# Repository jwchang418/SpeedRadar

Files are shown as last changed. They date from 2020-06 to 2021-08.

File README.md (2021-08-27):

# SpeedRadar

This project is designed by Jun-Wei Chang for a simple speed radar by using a few of electronic components.

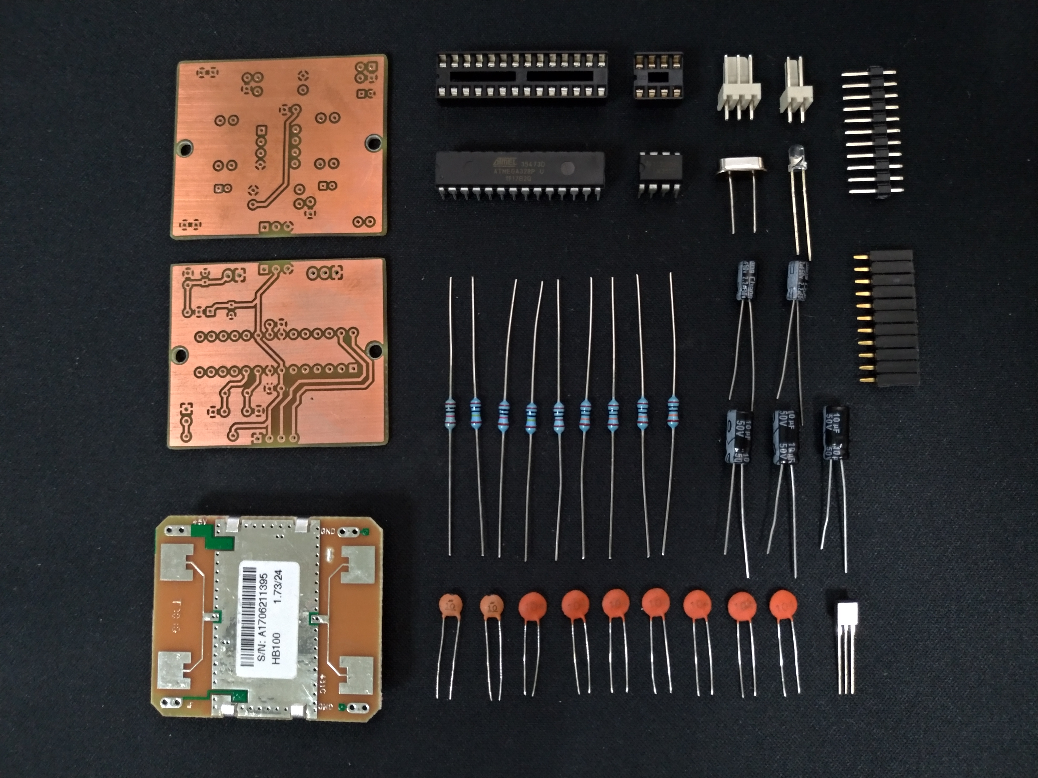
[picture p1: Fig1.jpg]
<br/>

Components list  
[here](https://github.com/jwchang418/SpeedRadar/blob/master/Components%20List.pdf)<br/>

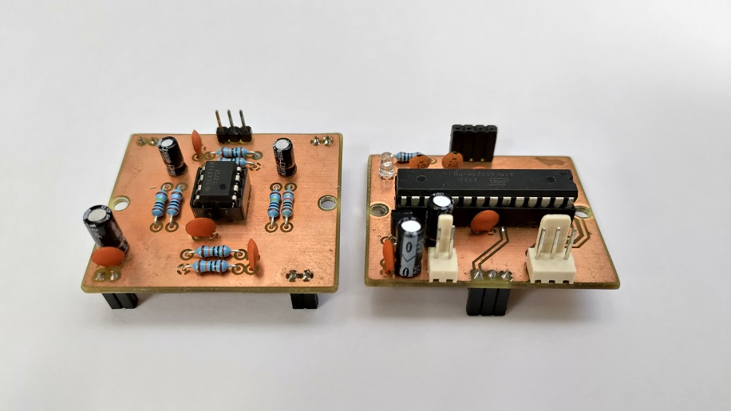
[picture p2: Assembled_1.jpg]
<br/>
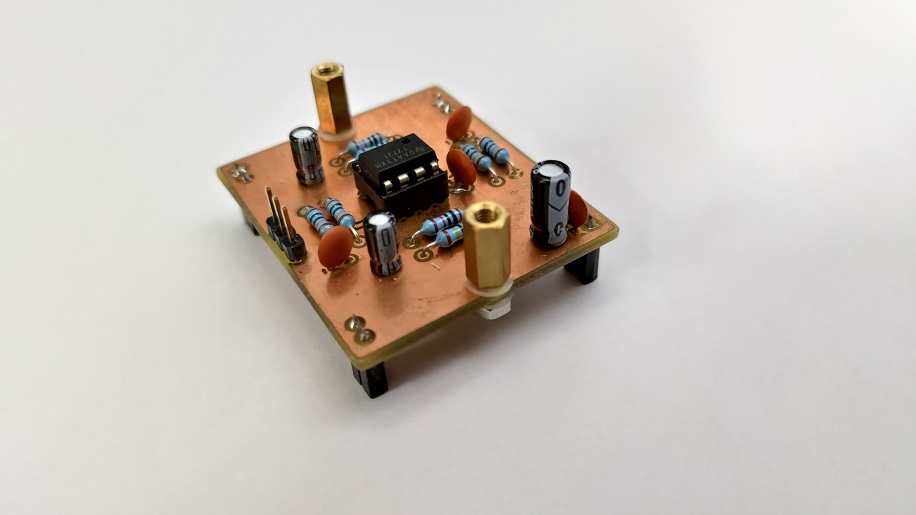
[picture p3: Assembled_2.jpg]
<br/>
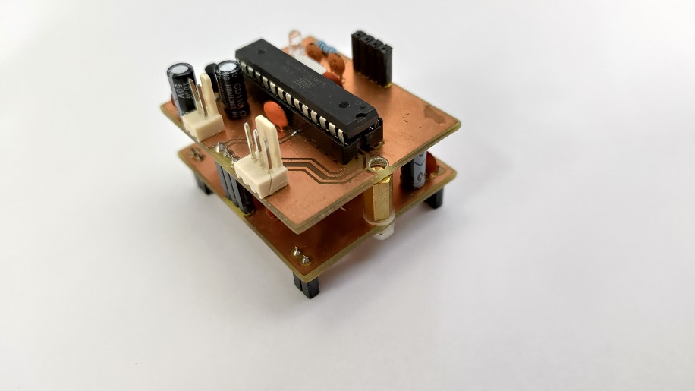
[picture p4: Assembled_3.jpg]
<br/>
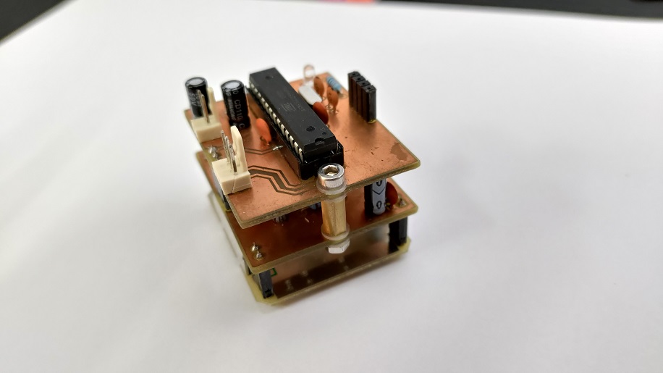
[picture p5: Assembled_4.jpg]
<br/>
Enjoy it !!

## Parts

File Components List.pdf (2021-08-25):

## Components List

Symbol | Value
C1 | 10uF
C2 | 0.1uF
C3 | 0.1uF
C4 | 0.1uF
C5 | 1uF
C6 | 0.1uF
C7 | 1uF
C8 | 0.1uF
C9 | 0.1uF
C10 | 10uF
C11 | 0.1uF
C12 | 10uF
C13 | 10pF
C14 | 10pF
D1 | LED
DC_in1 | 2 Pin Molex KK 254 Connector
HB1 | HB100
J1 | Conn_01x03
J2 | Conn_01x03
J3 | Conn_01x04
J4 | Conn_01x03
R1 | 100k
R2 | 100k
R3 | 10k
R4 | 1M
R5 | 100k
R6 | 100k
R7 | 10K
R8 | 200K
R9 | 1K
U1 | LM358
U2 | ATmega328P-PU
U3 | L78L05_TO92
Y1 | 16Mhz

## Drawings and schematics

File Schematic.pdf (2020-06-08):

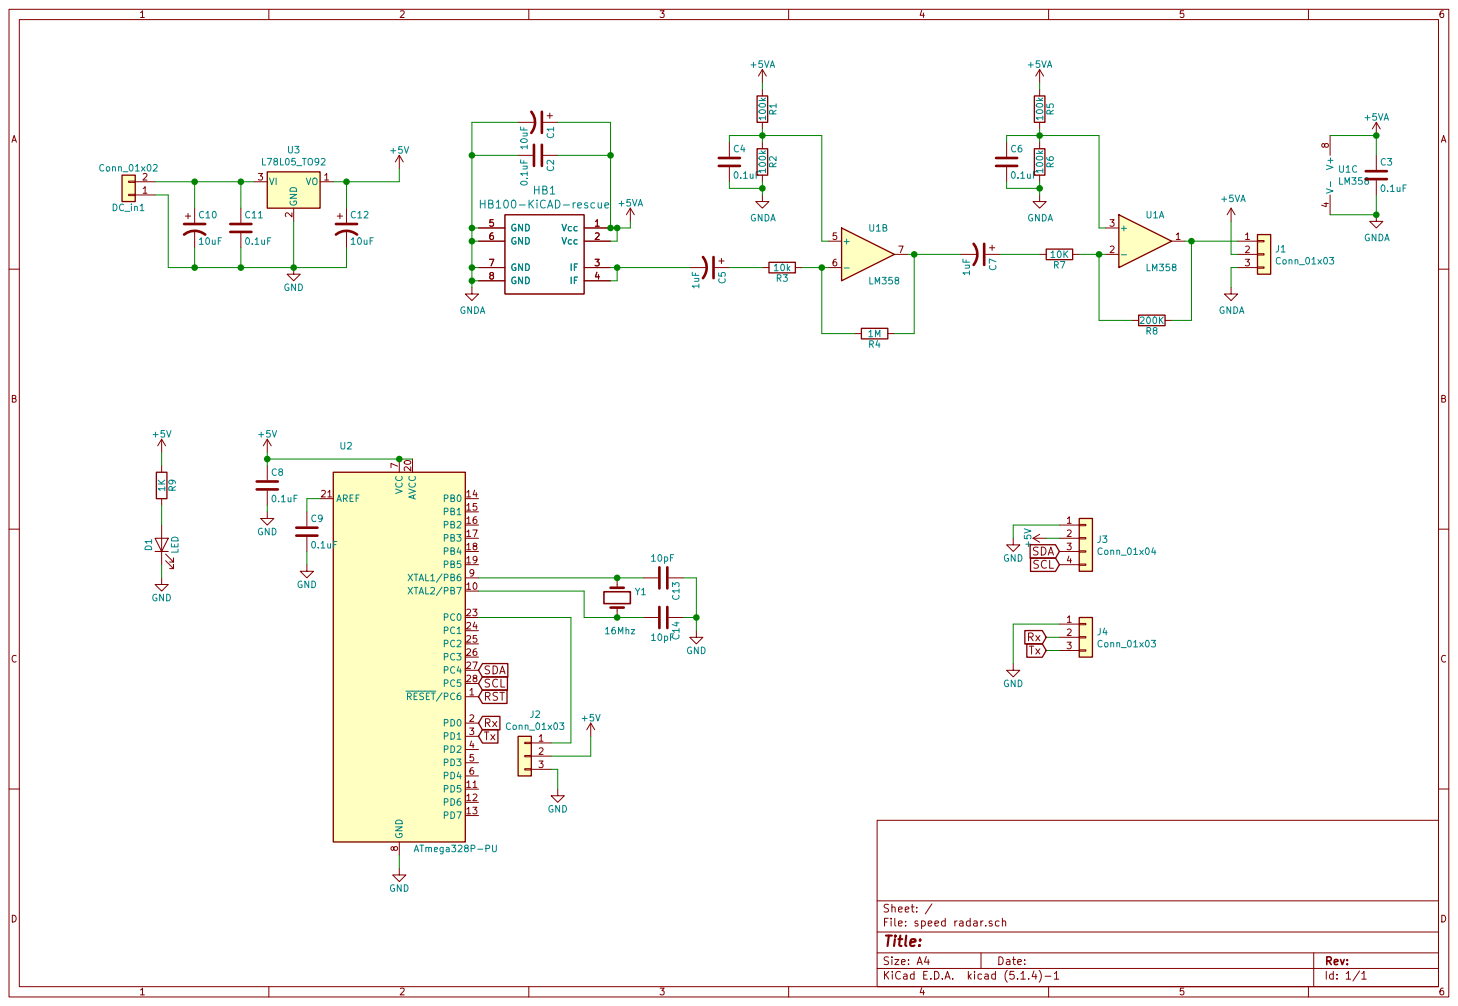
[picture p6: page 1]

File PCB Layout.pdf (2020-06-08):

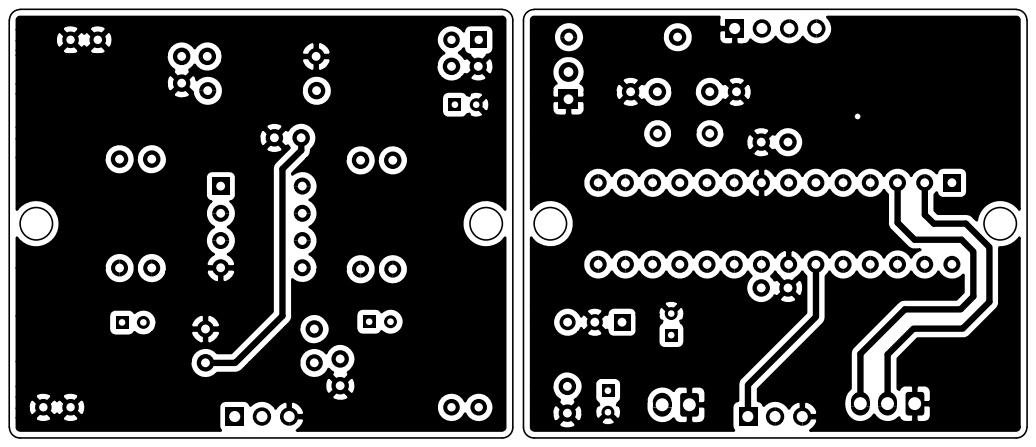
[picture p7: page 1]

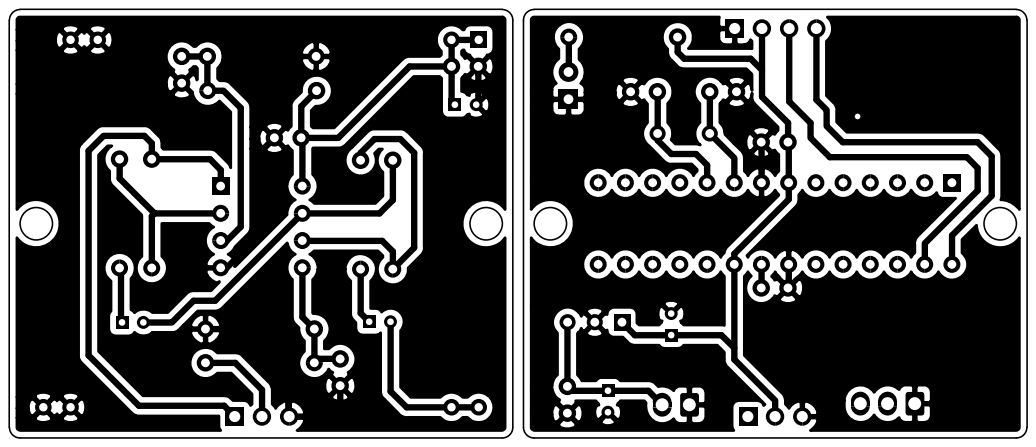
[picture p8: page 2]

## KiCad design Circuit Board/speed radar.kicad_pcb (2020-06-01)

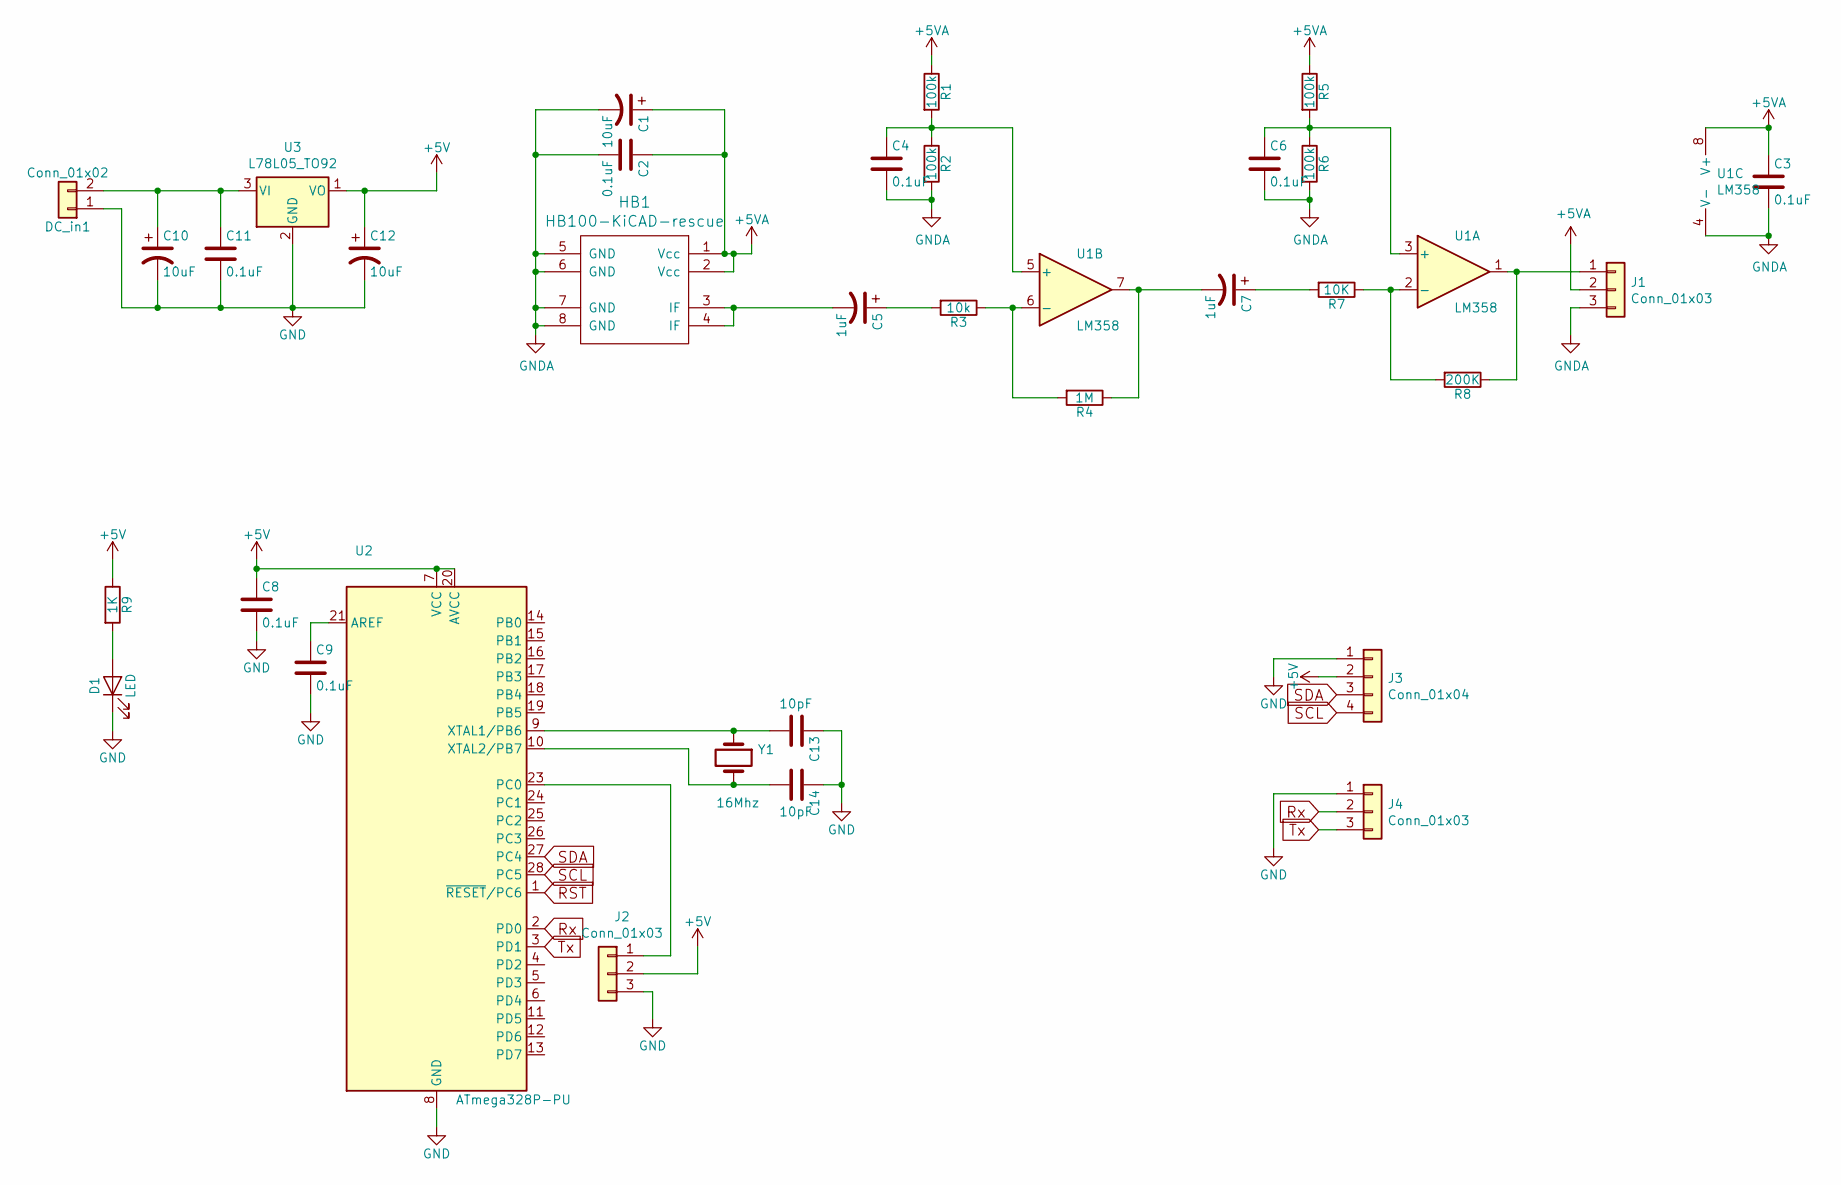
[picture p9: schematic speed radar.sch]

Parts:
C1, C10, C12: 10uF; CP_Radial_D4.0mm_P2.00mm
C2, C3, C4, C6, C8, C9, C11: 0.1uF; C_Disc_D3.0mm_W1.6mm_P2.50mm
C5, C7: 1uF; CP_Radial_D4.0mm_P2.00mm
C13, C14: 10pF; C_Disc_D3.0mm_W1.6mm_P2.50mm
D1: LED; LED_D3.0mm
DC_in1: Conn_01x02; Molex_KK-254_AE-6410-02A_1x02_P2.54mm_Vertical
HB1: HB100-KiCAD-rescue; HB100_ver2
J1, J2: Conn_01x03; PinHeader_1x03_P2.54mm_Vertical
J3: Conn_01x04; PinHeader_1x04_P2.54mm_Vertical
J4: Conn_01x03; Molex_KK-254_AE-6410-03A_1x03_P2.54mm_Vertical
R1, R2, R5, R6: 100k; R_Axial_DIN0207_L6.3mm_D2.5mm_P10.16mm_Horizontal
R3: 10k; R_Axial_DIN0207_L6.3mm_D2.5mm_P10.16mm_Horizontal
R4: 1M; R_Axial_DIN0207_L6.3mm_D2.5mm_P10.16mm_Horizontal
R7: 10K; R_Axial_DIN0207_L6.3mm_D2.5mm_P10.16mm_Horizontal
R8: 200K; R_Axial_DIN0207_L6.3mm_D2.5mm_P10.16mm_Horizontal
R9: 1K; R_Axial_DIN0207_L6.3mm_D2.5mm_P10.16mm_Horizontal
U1: LM358
U2: ATmega328P-PU; DIP-28_W7.62mm
U3: L78L05_TO92; TO-92_Inline_Wide
Y1: 16Mhz; Crystal_HC49-4H_Vertical

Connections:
+5V: C8.1, C12.1, J2.2, J3.2, R9.1, U2.7 (VCC), U2.20 (AVCC), U3.1 (VO)
+5VA: C1.1, C2.1, C3.1, HB1.1 (Vcc), HB1.2 (Vcc), J1.2, R1.1, R5.1, U1.8 (V+)
GND: C8.2, C9.2, C10.2, C11.2, C12.2, C13.1, C14.1, D1.1 (K), DC_in1.1, J2.3, J3.1, J4.1, U2.8 (GND), U2.22 (GND), U3.2 (GND)
GNDA: C1.2, C2.2, C3.2, C4.2, C6.2, HB1.5 (GND), HB1.6 (GND), HB1.7 (GND), HB1.8 (GND), J1.3, R2.2, R6.2, U1.4 (V-)
unnamed: C4.1, R1.2, R2.1, U1.5 (+)
unnamed: C5.1, R3.2
unnamed: C5.2, HB1.3 (IF), HB1.4 (IF)
unnamed: C6.1, R5.2, R6.1, U1.3 (+)
unnamed: C7.1, R7.2
unnamed: C7.2, R4.1, U1.7
unnamed: C9.1, U2.21 (AREF)
unnamed: C10.1, C11.1, DC_in1.2, U3.3 (VI)
unnamed: C13.2, U2.9 (XTAL1/PB6), Y1.1
unnamed: C14.2, U2.10 (XTAL2/PB7), Y1.2
unnamed: D1.2 (A), R9.2
unnamed: J1.1, R8.1, U1.1
unnamed: J2.1, U2.23 (PC0)
unnamed: R3.1, R4.2, U1.6 (-)
unnamed: R7.1, R8.2, U1.2 (-)
RST: U2.1 (~RESET~/PC6)
Rx: J4.2, U2.2 (PD0)
SCL: J3.4, U2.28 (PC5)
SDA: J3.3, U2.27 (PC4)
Tx: J4.3, U2.3 (PD1)

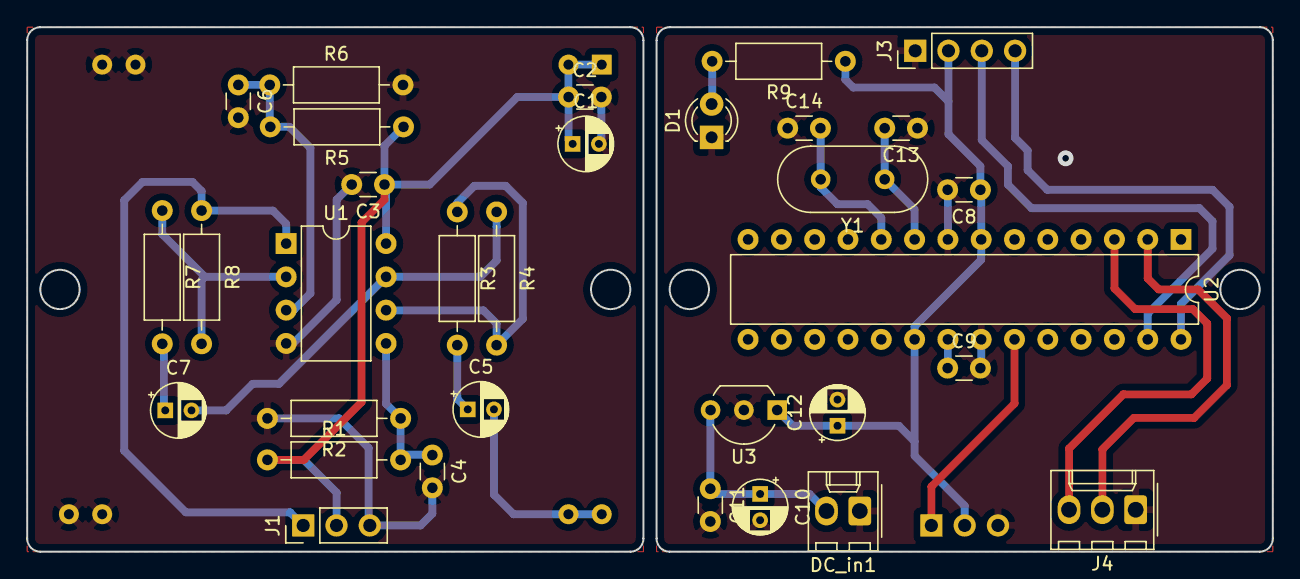
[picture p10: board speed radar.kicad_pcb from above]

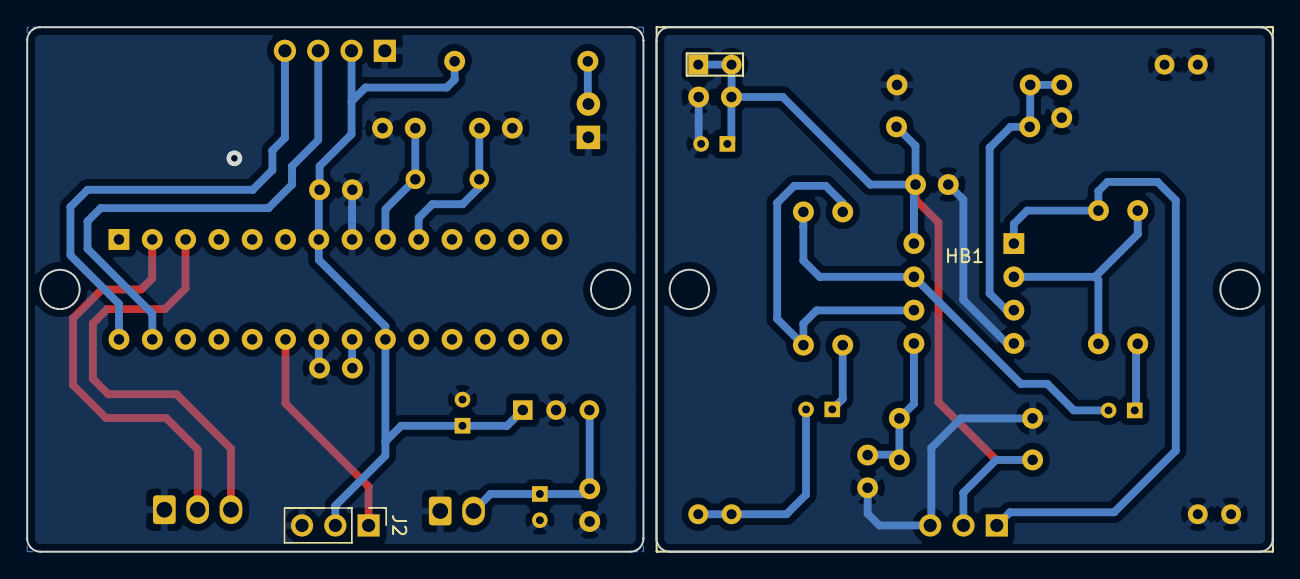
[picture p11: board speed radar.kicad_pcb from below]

Board: 2 copper layers, 95.0 x 40.0 mm, 34 parts (2 on the bottom side), 23 nets.

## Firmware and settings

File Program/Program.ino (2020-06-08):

/* This program uses i2c lcd library.
 * Please, make sure you have the lib in your development environment.
*/
#include <LiquidCrystal_I2C.h>
LiquidCrystal_I2C lcd(0x3F, 2, 1, 0, 4, 5, 6, 7, 3, POSITIVE);

unsigned long pin = 0;

void setup() {
  Serial.begin(19200);
}

void loop() {
  pin = pulseIn(14, HIGH);
  
  if (pin != 0) {
    float sp = 1000000 / pin;
    sp /= 19.49; 
    lcd.clear();
    lcd.setCursor(0, 0);
    lcd.print(sp);
    lcd.print("km/h");
    Serial.print(sp);
    Serial.println(" km/h");
  }
}

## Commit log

2020-06-08 Rename speed radar-cache.lib to KiCadFile/speed radar-cache.lib
2020-06-08 Rename speed radar-rescue.lib to KiCadFile/speed radar-rescue.lib
2020-06-08 Rename speed radar.kicad_pcb to KiCadFile/speed radar.kicad_pcb
    [speed radar.kicad_pcb]
2020-06-08 Rename speed radar.sch to KiCadFile/speed radar.sch
    [speed radar.sch]
2020-06-08 Rename speed radar.pro to KiCadFile/speed radar.pro
2020-06-08 Rename KiCadFile/speed radar-cache.lib to Circuit Board/speed radar-cache.lib
2020-06-08 Rename KiCadFile/speed radar-rescue.lib to Circuit Board/speed radar-rescue.lib
2020-06-08 Rename KiCadFile/speed radar.kicad_pcb to Circuit Board/speed radar.kicad_pcb
    [speed radar.kicad_pcb]
2020-06-08 Rename KiCadFile/speed radar.pro to Circuit Board/speed radar.pro
2020-06-08 Rename KiCadFile/speed radar.sch to Circuit Board/speed radar.sch
    [speed radar.sch]
